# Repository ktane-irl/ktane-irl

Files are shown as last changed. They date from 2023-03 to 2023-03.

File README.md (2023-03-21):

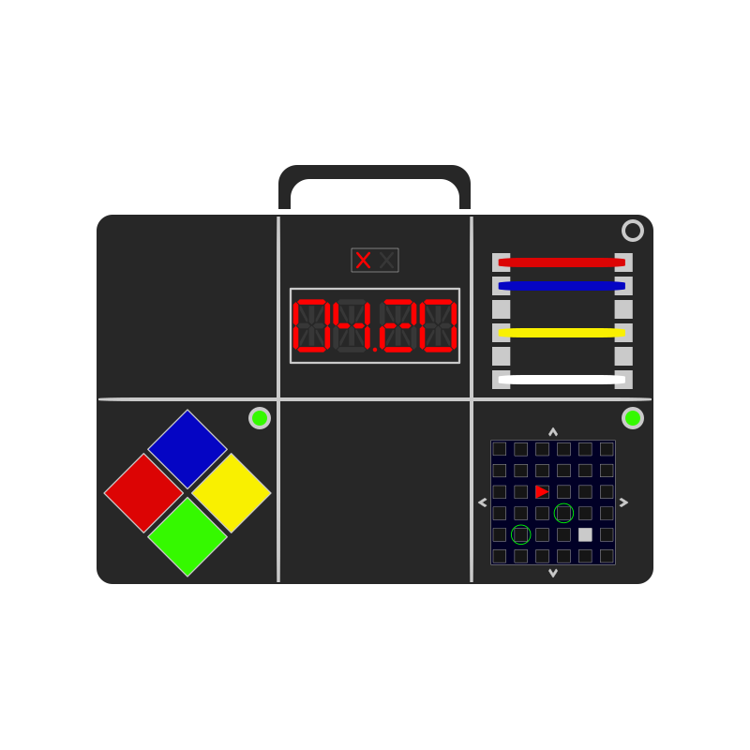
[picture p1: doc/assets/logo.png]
<h1> 

# KTANEirl

</h1>

[Keep Talking and nobody explodes](https://keeptalkinggame.com/) in real life!

<br>

KTANEirl is a modular in-hardware implementation of the famous puzzle video game KTANE.

## Modules

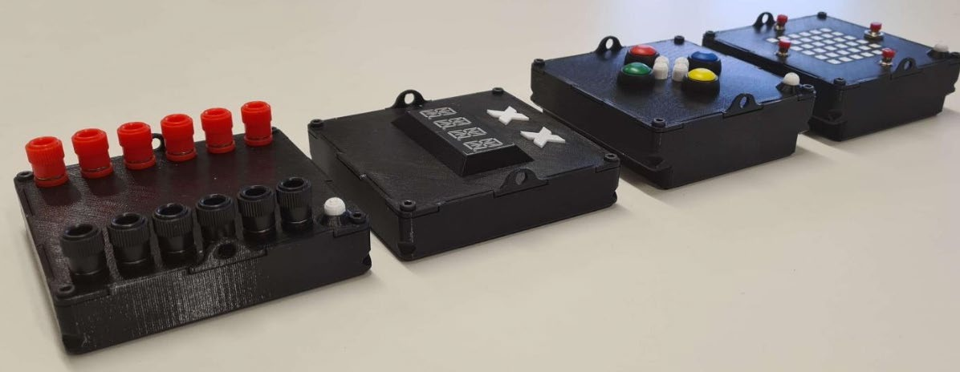
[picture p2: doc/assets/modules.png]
modules


The modules information can be found in the [modules](modules/README.md) folder.

## Master

The master information can be found in the [master](master/README.md) folder.

## Contributors

* Module implementations: [@FinnArtmann](https://github.com/FinnArtmann), [@andreasforstner](https://github.com/andreasforstner), [@RebekkaSeidenschwand](https://github.com/RebekkaSeidenschwand)
* package controller: [@ZaykorDE](https://github.com/ZaykorDE)
* module logic and game logic: [@Emergency1999](https://github.com/Emergency1999)
* API: [@thomasniefanger](https://github.com/thomasniefanger)
* frontend: [@ptrLx](https://github.com/ptrLx)
* package simulator: [@Emergency1999](https://github.com/Emergency1999)
* schematics: [@FinnArtmann](https://github.com/FinnArtmann), [@andreasforstner](https://github.com/andreasforstner), [@ZaykorDE](https://github.com/ZaykorDE)
* 3D modeling: [@Emergency1999](https://github.com/Emergency1999)

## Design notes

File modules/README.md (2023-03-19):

# KTANEirl Modules

This folder structure contains the [**firmware code**](#firmware), [**circuit schematics**](#circuit-schematics) and [**3D files**](#3d-files) of the KTANEirl modules.

## Firmware

This code is the firmware for the KTANEirl project. Each module has a specific firmware code  which runs on the module's Arduino nano.

### Requirements

#### VSCode with PlatformIO

- Install VSCode from the official [Website](https://code.visualstudio.com/)

- install the [PlatformIO IDE](https://marketplace.visualstudio.com/items?itemName=platformio.platformio-ide) extension from the marketplace via the extensions menu on the left on VSCode

#### Install dependencies

Dependencies should be installed automatically by PlatformIO.
It uses a *platform.ini* file from each specific module directory to find the required dependencies.

### Usage

Open the [firmware.code-workspace](../firmware.code-workspace)

### Build

- Select the Module to be built in the bottom bar in VSCode
- Build it using CTRL+ALT+B

### Deploy

- Connect your device to the USB port of the Arduino nano
- Upload the firmware with the keybinding CTRL+ALT+U

### Monitor

- Open the Serial Port Monitor with CTRL+ALT+S

## Circuit schematics

The circuit schematics are made with KiCad. To open the schematics, you need to install KiCad from the official [Website](https://kicad.org/).

## 3D files

The 3D files are created in Onshape and exported as STL files.

To add or change 3D files, you need to create an account on [Onshape](https://www.onshape.com/). Then you can copy [this project](https://cad.onshape.com/documents/d60e5291216102ee16b1bc50/w/64ba86776bbcf32b675bc0db/e/fd5f7a77dd2c26ad647590be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) and make your changes.

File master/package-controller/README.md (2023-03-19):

# KTANEirl Package Controller

This code is the package controller for the KTANEirl project. It is designed to run on a raspberry pi and create a connection with the backend through TCP and with the modules thorugh SPI.

## Setup
For the setup of the package controller two libarires must be installed. In order to do so the following two scripts need to be executed on the raspberry pi:
* install-bcm.sh
* install-sockpp.sh

## Usage
To start the the package controlle the file spi-package-controller needs to be executed. This can be done with the following command:
* sudo spi-package-controller

## Building the code
For building the project a Makefile has been created. After changed to the code this can be executed through the following command:
* make

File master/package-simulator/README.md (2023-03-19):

# KTANEirl Package Simulator

This code is the package simulator for the KTANEirl project. It is designed to run on a raspberry pi and send simulated SPI commands to the connected module.

## Setup

### Install dependencies

```bash
yarn install
```

## Usage

First, change the byte string, which should represent the SPI command, in [app.ts](src/app.ts).

Then, start the simulator:

```bash
yarn serve
```

The output then shows the sent and received bytes from the module.

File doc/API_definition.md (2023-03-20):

# /api

## /api/status

### /api/connected-modules

> GET

```json
{
    "slot_0": {
        "name": "Case",
        "version": 1,
        "configuration_target_reached": false,
    },
    "slot_1": {
        "name": "ClockModule",
        "version": 1,
        "configuration_target_reached": true
    },
    "slot_2": {
        "name": "TheButton",
        "version": 1,
        "configuration_target_reached": false
    },
    "slot_3": {
        "name": "Keypads",
        "version": 1,
        "configuration_target_reached": false
    },
    "slot_4": {
        "name": "Wires",
        "version": 1,
        "configuration_target_reached": false
    },
    "slot_5": {
        "name": "not_connected",
        "version": 0,
        "configuration_target_reached": true
    },
    "slot_6": {
        "name": "not_connected",
        "version": 0,
        "configuration_target_reached": true
    },
    "slot_7": {
        "name": "TheButton",
        "version": 1,
        "configuration_target_reached": false
    },
    "slot_8": {
        "name": "not_connected",
        "version": 0,
        "configuration_target_reached": true
    },
    "slot_9": {
        "name": "not_connected",
        "version": 0,
        "configuration_target_reached": true
    },
    "slot_10": {
        "name": "CapacitorDischarge",
        "version": 1,
        "configuration_target_reached": false
    },
    "slot_11": {
        "name": "not_connected",
        "version": 0,
        "configuration_target_reached": true
    },
    "slot_12": {
        "name": "not_connected",
        "version": 0,
        "configuration_target_reached": true
    }   
}
```

### /api/Case/1/[0-12]

> GET

```json
{
  "serialNumber": "AL50F2",
  "indicatorText": ["Empty","SND","CLR","CAR"],
  "indicatorLed": [false, false, false, false, false],
  "batteries": [true,false,true,false,true,false],
  "ports": {
    "DVI_D": false,
    "Parallel": true,
    "PS_2": false,
    "Serial": false,
    "Cinch": false
    }
}
```

> PUT

```json
{
   "indicatorLed": [true, false, true, true, true]
}
```

### /api/ClockModule/1/[0-12]

> GET

```json
{
    "secondsLeft": 20,
    "strikeLed": [true, false]    
}
```

> PUT

```json
{
    "secondsLeft": 20,
    "strikeLed": [true, false]  
}
```

### /api/Wires/1/[0-12]

> GET

<!-- color 0 means not connected -->
<!-- see wires type in common -->

```json
{
    "wiresColor": [0, 1, 2, 4, 5, 6],
    "statusLed": {
        "red": true,
        "green": false
    }
}

> PUT

```json
{   
    "statusLed": {
        "red": false,
        "green": false
    }
}
```

### /api/SimonSays/1/[0-12]

> GET

```json
{
    "led":{
        "red": true,
        "green": false,
        "yellow": false,
        "blue": false
    },
    "button": {
        "red": true,
        "green": false,
        "yellow": false,
        "blue": false
    },
    "statusLed": {
        "red": true,
        "green": false
    }
}
```

> PUT

```json
{
    "led": {
        "red": true,
        "green": false,
        "yellow": false,
        "blue": false
    },
    "statusLed": {
        "red": false,
        "green": false
    }
}
```

### /api/Mazes/1/[0-12]

> GET

```json
{
    "button": {
        "top": true,
        "right": false,
        "bottom": false,
        "left": false
    },
    "wallMatrix": [[true],[false]],
    "special": {
        "circle1": {"x": 1, "y": 2},
        "circle2": {"x": 3, "y": 4},
        "player": {"x": 5, "y": 6},
        "target": {"x": 7, "y": 8}
    },
    "statusLed": {
        "red": true,
        "green": false
    }
}
```

> PUT

```json
{
    "wallMatrix": [[true],[false]],
    "special": {
        "circle1": {"x": 1, "y": 2},
        "circle2": {"x": 3, "y": 4},
        "player": {"x": 5, "y": 6},
        "target": {"x": 7, "y": 8}
    },
    "statusLed": {
        "red": true,
        "green": false
    }
    
}
```

<!-- ### /api/Button/1/[0-12]

not implemented.

### /api/Keypad/1/[0-12]

not implemented.

### /api/WhosOnFirst/1/[0-12]

not implemented.

### /api/Memory/1/[0-12]

not implemented.

### /api/MorseCode/1/[0-12]

not implemented.

### /api/ComplicatedWires/1/[0-12]

not implemented.

### /api/WireSequences/1/[0-12]

not implemented.

### /api/Passwords/1/[0-12]

not implemented.

### /api/VentingGas/1/[0-12]

not implemented.

### /api/Knobs/1/[0-12]

not implemented.

### /api/CapacitorDischarge/1/[0-12]

not implemented. -->

## /api/play

### /api/play/config

> PUT

```json
{
    "available_modules": [
        {"name": "Wires", "count": 0},
        {"name": "TheButton", "count": 0},
        {"name": "Keypads", "count": 0},
        {"name": "SimonSays", "count": 1},
        {"name": "WhosOnFirst", "count": 0},
        {"name": "Memory", "count": 1},
        {"name": "MorseCode", "count": 2},
        {"name": "ComplicatedWires", "count": 1},
        {"name": "WireSequences", "count": 2},
        {"name": "Mazes", "count": 0},
        {"name": "Passwords", "count": 2},
        {"name": "VentingGas", "count": 0},
        {"name": "CapacitorDischarge", "count": 0},
        {"name": "Knobs", "count": 0}
    ],
    "count_of_wished_modules": 5,
    "seconds_to_play": 0,
    "severity_level": 1
}
```

(Response of generated configuration)

> GET

```json
["Wires", "SimonSays", "Wires", "TheButton"]
```

### /api/play/config/Case/1/[0-12]

> GET

```json
{
    "caseTarget":{
        "serialNumber": "AL5OF2",
        "indicatorText": ["SND", "CLR", "CAR", "NSA", "SIG"],
        "indicatorLed":[true,false,true,false,false],
        "batteries": [true, false, false, false, false, false],
        "ports": {
            "DVI-D" : false,
            "Parallel": true,
            "PS/2": false,
            "RJ-45" : false,
            "Serial": false,
            "Cinch": false
        }
    },
    "caseState":{
        "serialNumber": "JG0IZ1",
        "indicatorText": ["IND", "MSA", "FRk", "NSA", "SIG"],
        "indicatorLed":[false,false,true,false,false],
        "batteries": [true, true, true, false, false, false],
        "ports": {
            "DVI-D" : true,
            "Parallel": false,
            "PS/2": false,
            "RJ-45" : false,
            "Serial": false,
            "Cinch": false
        }
    }
}
```

### /api/play/config/Wires/1/[0-12]

> GET

```json
// "black" / "blue" / "" / "red" / "white" / "yellow"
{
    "wiresTarget":{

        "statusLed":{
            "red": false,
            "green": false
        },
        "wiresColor":[4,4,1,5,1,3]
    },
    "wiresState":{

        "statusLed":{
            "red": false,
            "green": true
        },
        "wiresColor":[2,3,1,4,5,3]
    }
}
```

<!-- ### /api/play/config/TheButton/1/[0-12]

not implemented.

### /api/play/config/Keypads/1/[0-12]

not implemented.

### /api/play/config/WhosOnFirst/1/[0-12]

not implemented.

### /api/play/config/Memory/1/[0-12]

not implemented.

### /api/play/config/MorseCode/1/[0-12]

not implemented.

### /api/play/config/ComplicatedWires/1/[0-12]

not implemented.

### /api/play/config/WireSequences/1/[0-12]

not implemented.

### /api/play/config/Mazes/1/[0-12]

not implemented.

### /api/play/config/Passwords/1/[0-12]

not implemented.

### /api/play/config/VentingGas/1/[0-12]

not implemented.

### /api/play/config/CapacitorDischarge/1/[0-12]

not implemented.

### /api/play/config/Knobs/1/[0-12]

not implemented. -->

### /api/play/SetGameState

**gamemodes**:

* test_idle
* setup
* playing

> PUT

```json
{
    "gamemode": "playing"
}
```

> GET

```json
{
    "gamemode": "playing"
}
```

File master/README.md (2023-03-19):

# KTANEirl Master

master components

This folder contains all software running on the raspberry pi. This includes the [frontend](frontend/README.md), the [backend](backend/README.md) and the [package-controller](package-controller/README.md).

To setup the pi, run the [setup script](setup-pi.sh) on it.

To test basic firmware functionality, use the [package-simulator](package-simulator/README.md).

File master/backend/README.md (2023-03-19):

# KTANEirl Backend

This code is the backend for the KTANEirl project. It is designed to run on a raspberry pi and communicate with the frontend via the API.

## Requirements

### **Node.js >= 18.12.0**

Download from [nodejs.org](https://nodejs.org/en/download/) or use

```bash
curl -fsSL https://deb.nodesource.com/setup_18.x | sudo -E bash -
sudo apt-get install -y nodejs
```

on Linux Ubuntu or use the [setup script](../setup-pi.sh) on the pi.

### **yarn >= 1.22.19**

use this to install yarn:

```bash
npm install -g yarn
```

## Setup

### Install dependencies

```bash
yarn install
```

## Usage

### Start in normal mode

This command builds and the starts the backend.

```bash
yarn serve
```

### Start in simulator mode

**Start with API dummy-mode:**  
Use this if the Backend does not yet have the needed Module.

```bash
yarn serve-api
```

**Start with simulated SPI:**  
If the Backend class is fully implemented, use this to simulate the SPI communication.
The simulated commands can be changed in [app.sim.ts](src/app.sim.ts)

```bash
yarn serve-sim
```

### Other commands

| Command | Description |
| --- | --- |
| `yarn build` | Build the project |
| `yarn tsc` | Automatically build the project on changes |
| `yarn lint` | Lint the project |
| `yarn auto` | Run in normal mode and restart on changes |
| `yarn auto-api` | Run in dummy-mode and restart on changes |
| `yarn auto-sim` | Run in simulated SPI mode and restart on changes |
| `yarn clean` | Delete all build files |
| `yarn test` | Run all tests |
| `yarn autotest` | Automatically run all tests on changes |

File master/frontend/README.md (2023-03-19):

# KTANEirl Frontend

This code is the frontend for the KTANEirl project. It is designed to run on a raspberry pi and communicate with the backend via the API.

## get started

* setup and start dev container (See <https://code.visualstudio.com/docs/devcontainers/create-dev-container>)
* `cd master/frontend`
* `yarn`
* `yarn serve`

<!-- ## create a vue app (don't do this, it's already created)
* `cd master`
* `vue create ktaneirl`  
  * Manually select features
  * Select Babel, TypeScript, Progressive Web App (PWA) Support, Router, Linter / Formatter, Unit Testing
  * 2.x (as vuetify does not support vue3 currently)
  * Confirm everything
* `cd ktaneirl`
* `vue add -D vuetify`
* `yarn add express typescript ts-node nodemon @types/node express @types/express`
* `yarn serve` -->

## add a module / version

1. `components/testmode`: Copy VersionComponentDummy and align to other module code
2. `views/TestmodeView.vue`: Import component; add to components const; add case in show_component_dialog

## initial setup for production

to setup backend and frontend on the pi, run the [setup script](../setup-pi.sh) on it.

## deployment

to deploy the frontend, run the [deploy script](../deploy-frontend.sh) on your local machine.

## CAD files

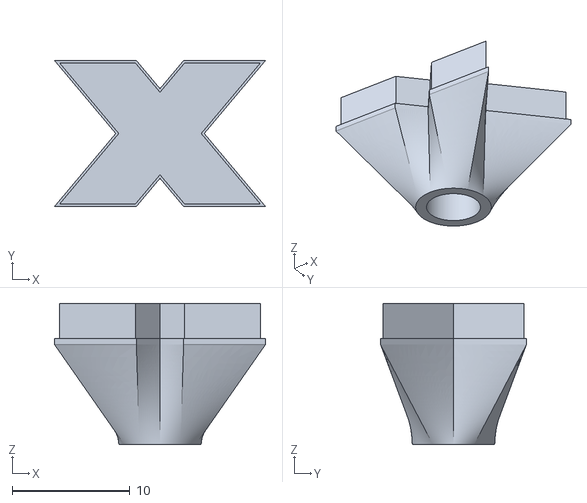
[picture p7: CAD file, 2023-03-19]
modules/01-clockModule/CM01-3d-design/CM01-Xled.stl
17.9 x 12.4 x 12.0

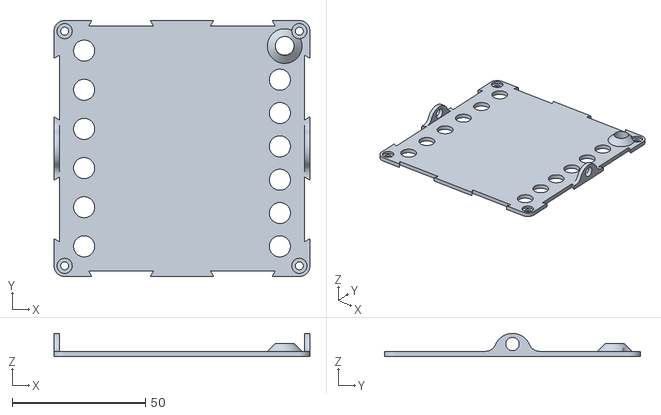
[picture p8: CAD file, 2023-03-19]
modules/02-wires/WI01-3d-design/WI01-ModuleTop.stl
96.0 x 96.0 x 8.70

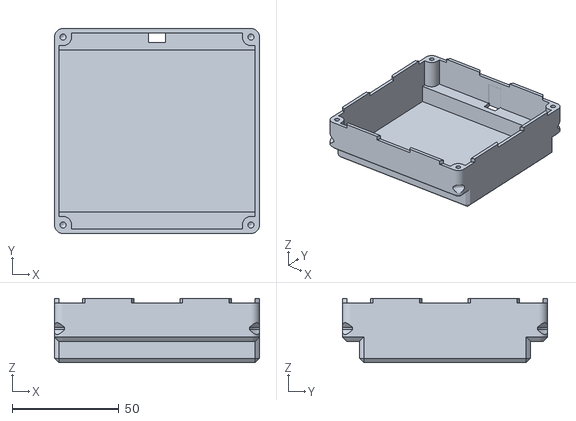
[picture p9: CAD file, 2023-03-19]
modules/05-simonSays/SS01-3d-design/SS01-ModuleBottom.stl
96.0 x 96.0 x 30.2

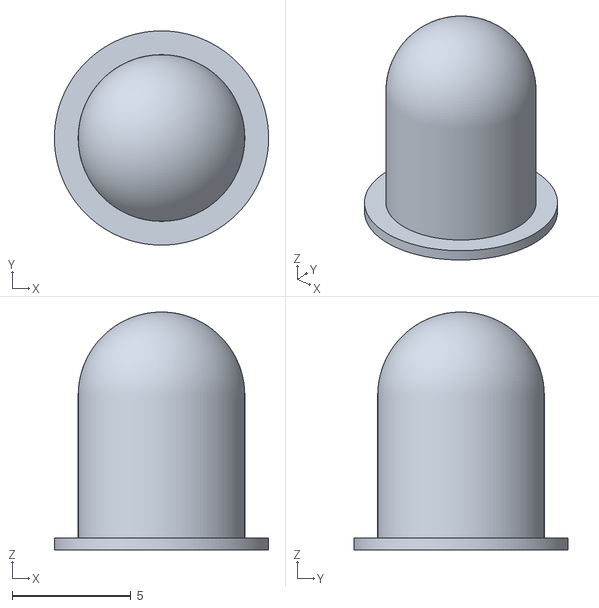
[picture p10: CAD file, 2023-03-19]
modules/02-wires/WI01-3d-design/WI01-LED.stl
9.00 x 9.00 x 10.0

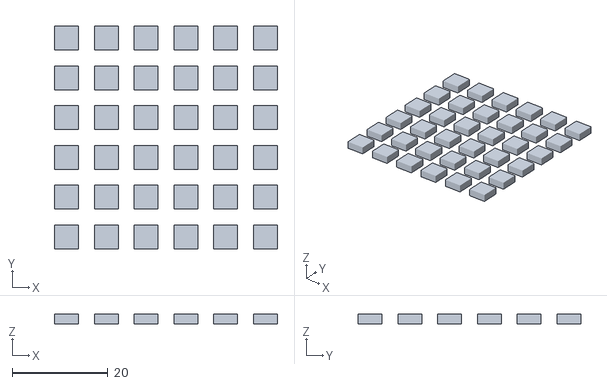
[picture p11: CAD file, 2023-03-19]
modules/11-mazes/MA01-3d-design/MA01-ModuleTop-White.stl
46.5 x 46.5 x 2.00

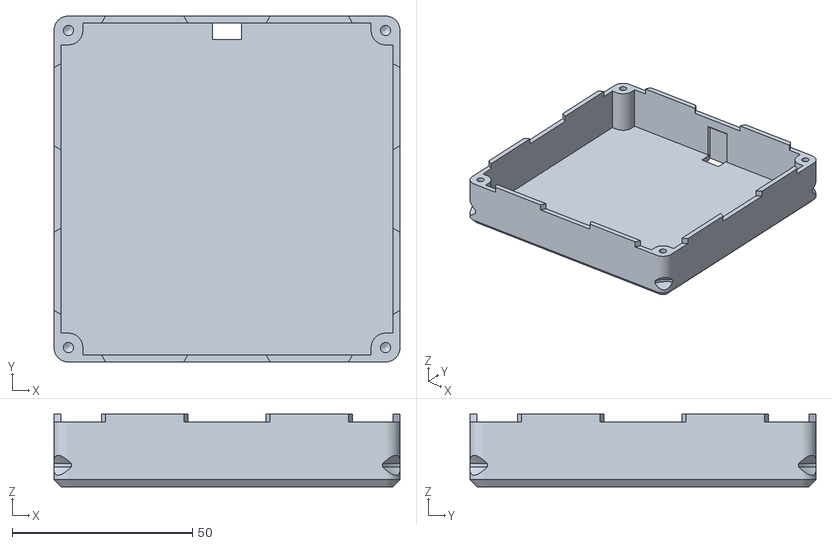
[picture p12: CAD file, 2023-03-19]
modules/01-clockModule/CM01-3d-design/CM01-ModuleBottom.stl
96.0 x 96.0 x 20.2

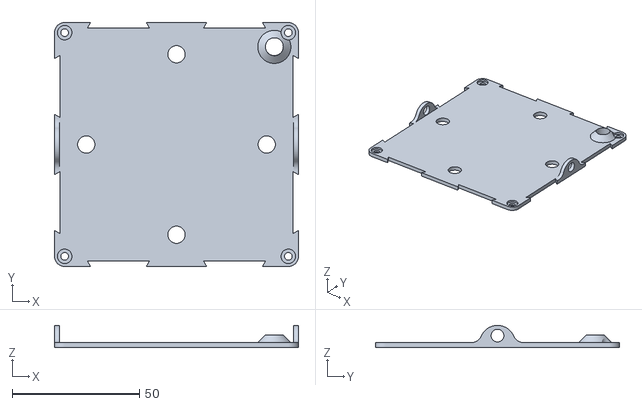
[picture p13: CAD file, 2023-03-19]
modules/11-mazes/MA01-3d-design/MA01-ModuleTop.stl
96.0 x 96.0 x 8.70

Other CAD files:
modules/11-mazes/MA01-3d-design/MA01-ModuleTop-Black.stl
modules/01-clockModule/CM01-3d-design/CM01-ModuleTop.stl
modules/05-simonSays/SS01-3d-design/SS01-ModuleTop.stl

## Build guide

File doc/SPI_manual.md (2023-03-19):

# SPI manual

all messages consist of 4 parts:

* 1     byte  CMD:  the command describing the action to be taken (0x01 - 0xFE)
* 1     byte  LEN:  the length of the DATA bytes
* 0-255 bytes DATA: the data to be sent or received
* 1     byte  CRC:  the CRC of the message, suing the Arduino internal CRC8 function

All Commands sent from client to the master need to be acknowledged by the master. The master will send a message with the same CMD as the original message, LEN = 1 and DATA with the event counter from the client message.

There is one exception for the SPI test:  
When CMD=0xEA, LEN=0xA5  
The SPI tests consists of 255 data bytes, using this algorithm:  
`data_0 = 0x01, data_i = (data_(i-1) * 5 + 1) % 256`  
As soon as the SPI test is done, the master and the client create error count messages (see [global](#global)).  
The client sends this as usual over SPI, the master injects the package as if it were received per SPI.

## IDs

### Module IDs

| ID dec | SHORT | NAME |
| -----: | ----: | --- |
| 0 | CA | Case |
| 1 | CM | Clock Module |
| 2 | WI | Wires |
| 3 | TB | The Button |
| 4 | KP | Keypads |
| 5 | SS | Simon Says |
| 6 | WF | Who’s on First |
| 7 | ME | Memory |
| 8 | MC | Morse Code |
| 9 | CW | Complicated Wires |
| 10 | WS | Wire Sequences |
| 11 | MA | Mazes |
| 12 | PW | Passwords |
| 16 | VG | Venting Gas |
| 17 | CD | Capacitor Discharge |
| 18 | KN | Knobs |

### Color IDs (3 bit)

| ID | COLOR |
| ----- | --- |
| 0b000 | not connected / off |
| 0b001 | black |
| 0b010 | blue |
| 0b011 | green |
| 0b100 | red |
| 0b101 | yellow |
| 0b110 | white |

### Error codes (8 bit)

| ID  | ERROR CODE |
| --- | --- |
| 0 | NoError |
| 1 | CRCError |
| 2 | InvalidCommand |
| 3 | InvalidDataLength |
| 4 | AcknowledgeError |
| 5 | BufferOverflow |
| | |
| 10  | DisplayConnectionError |

## GLOBAL

MASTER->SLAVE
| CMD  | NAME |  LEN | DATA DESCRIPTION |
| ---- | --- | ---: | --- |
| 0x00 | reserved for NO_CMD | | |
| 0xFF | reserved for NOT_CONNECTED | | |
| 0xEA | reserved for SPI test | | |
| | | | |
| 0xFE | ACK Error code | 1 | error counter |
| 0xFD | ACK module initialization  | 1 | ID |
| 0xFC | request module reset | 0 | |

SLAVE->MASTER
| CMD  | NAME | SENT CONDITION |  LEN | DATA DESCRIPTION |
| ---- | --- | --- | ---: | --- |
| 0x00 | reserved for NO_CMD | | | |
| 0xFF | reserved for NOT_CONNECTED | | | |
| 0xEA | reserved for SPI test | | | |
| 0xEB | Error count on MOSI (sent by slave) | on SPI test done | 1 | number of byte errors |
| 0xEC | Error count on MISO (injected by master) | on SPI test done | 1 | number of byte errors |
| | | | | |
| 0xFE | Error code | on error | 2 | error counter, error code |
| 0xFD | module ID+version | when not initialized | 2 | ID, version |

## 00 Case

### CA-01

MASTER->SLAVE
| CMD  | NAME |  LEN | DATA DESCRIPTION |
| ---- | --- | ---: | --- |
| 0x01 | set 5 indicator lights | 1 | 0b___43210: |
| | | | 0-4: indicator (1 = ON, 0 = OFF) |
| 0x02 | ACK 6 battery slot states | 1 | counter |

SLAVE->MASTER
| CMD  | NAME | SENT CONDITION |  LEN | DATA DESCRIPTION |
| ---- | --- | --- | ---: | --- |
| 0x02 | 6 battery slot states | when initialized or changed | 2 | counter, 0b__543210: |
| | | | | 0-5: battery slots (1 = FILLED, 0 = EMPTY) |

## 01 Clock Module

### CM-01

MASTER->SLAVE
| CMD  | NAME |  LEN | DATA DESCRIPTION |
| ---- | --- | ---: | --- |
| 0x01 | game time left and errors | 2 | 0bLR__TTTT 0bTTTTTTTT: |
| | | | L = left "X" LED (1 = ON, 0 = OFF) |
| | | | R = right "X" LED (1 = ON, 0 = OFF) |
| | | | T = time left in seconds (12 bit, MSB left to LSB right) |

## 02 Wires

### WI-01

MASTER->SLAVE
| CMD  | NAME |  LEN | DATA DESCRIPTION |
| ---- | --- | ---: | --- |
| 0x01 | RG LED | 1 | 0b______RG: |
| | | | R = Red LED (1 = ON, 0 = OFF) |
| | | | G = Green LED (1 = ON, 0 = OFF) |
| 0x02 | ACK wire states | 1 | counter |

SLAVE->MASTER
| CMD  | NAME | SENT CONDITION |  LEN | DATA DESCRIPTION |
| ---- | --- | --- | ---: | --- |
| 0x02 | wire states | when initialized or changed | 4 | counter, 0b__555444 0b__333222 0b__111000: |
| | | | | 0=top to 5=bottom: [color IDs](#color-ids-3-bit) |

## 03 The Button

## 04 Keypads

## 05 Simon Says

### SS-01

MASTER->SLAVE
| CMD  | NAME |  LEN | DATA DESCRIPTION |
| ---- | --- | ---: | --- |
| 0x01 | RG LED | 1 | 0b______RG: |
| | | | R = Red LED (1 = ON, 0 = OFF) |
| | | | G = Green LED (1 = ON, 0 = OFF)  |
| 0x02 | LED states | 1 | 0b____BYGR |
| | | | B = blue LED (1 = ON, 0 = OFF) |
| | | | Y = yellow LED (1 = ON, 0 = OFF) |
| | | | G = green LED  (1 = ON, 0 = OFF) |
| | | | R = red LED (1 = ON, 0 = OFF) |
| 0x03 | ACK button states | 1 | counter |

SLAVE->MASTER
| CMD  | NAME | SENT CONDITION |  LEN | DATA DESCRIPTION |
| ---- | --- | --- | ---: | --- |
| 0x03 | button states | when initialized or changed | 2 | counter, 0b____BYGR |
| | | | | B = blue button state (1 = PRESSED, 0 = RELEASED) |
| | | | | Y = yellow button state (1 = PRESSED, 0 = RELEASED) |
| | | | | G = green button state  (1 = PRESSED, 0 = RELEASED) |
| | | | | R = red button state (1 = PRESSED, 0 = RELEASED) |

## 06 Who’s on First

## 07 Memory

## 08 Morse Code

### MC-01

Morse Code Frequencies:
| Code | Frequency |
| ---- | --- |
| 0x0  | 3.505 MHz |
| 0x1  | 3.515 MHz |
| 0x2  | 3.522 MHz |
| 0x3  | 3.532 MHz |
| 0x4  | 3.535 MHz |
| 0x5  | 3.542 MHz |
| 0x6  | 3.545 MHz |
| 0x7  | 3.552 MHz |
| 0x8  | 3.555 MHz |
| 0x9  | 3.565 MHz |
| 0xA  | 3.572 MHz |
| 0xB  | 3.575 MHz |
| 0xC  | 3.582 MHz |
| 0xD  | 3.592 MHz |
| 0xE  | 3.595 MHz |
| 0xF  | 3.600 MHz |

MASTER->SLAVE
| CMD  | NAME |  LEN | DATA DESCRIPTION |
| ---- | --- | ---: | --- |
| 0x01 | RG LED | 1 | 0b______RG: |
| | | | R = Red LED (1 = ON, 0 = OFF) |
| | | | G = Green LED (1 = ON, 0 = OFF) |
| 0x02 | ACK button and frequency | 1 | counter |
| 0x03 | morse led | 1 | 0b_______L: |
| | | | L = LED (1 = ON, 0 = OFF) |

SLAVE->MASTER
| CMD  | NAME | SENT CONDITION |  LEN | DATA DESCRIPTION |
| ---- | --- | --- | ---: | --- |
| 0x02 | button and frequency | when button or freq changed | 2 | counter, 0b000BFFFF |
| | | | | B = button state |
| | | | | F = frequency code  |

## 09 Complicated Wires

## 10 Wire Sequences

## 11 Mazes

### MA-01

Maze positioning:
| ROW\COL | 0 | 1 | 2 | 3 | 4 | 5 |
| --- | --- | --- | --- | --- | --- | --- |
| 0 | 0 | 1 | 2 | 3 | 4 | 5 |
| 1 | 6 | 7 | 8 | 9 | 10  | 11  |
| 2 | 12  | 13  | 14  | 15  | 16  | 17  |
| 3 | 18  | 19  | 20  | 21  | 22  | 23  |
| 4 | 24  | 25  | 26  | 27  | 28  | 29  |
| 5 | 30  | 31  | 32  | 33  | 34  | 35  |

Special type codes:
| ID  | color | DESCRIPTION |
| --- | --- | --- |
| 0 | green | Circle 1 to identify labyrinth |
| 1 | green | Circle 2 to identify labyrinth |
| 2 | white | position of player |
| 3 | red pulsing | red turning triangle position of target |

MASTER->SLAVE
| CMD  | NAME |  LEN | DATA DESCRIPTION |
| ---- | --- | ---: | --- |
| 0x01 | RG LED | 1 | 0b______RG: |
| | | | R = Red LED (1 = ON, 0 = OFF) |
| | | | G = Green LED (1 = ON, 0 = OFF) |
| 0x02 | ACK button states  | 1 | counter |
| 0x03 | Red wall positions | 5 | 0b01234567 0b89..... |
| | | | sets red positions in matrix above |
| 0x04 | Special positions  |  1-4 | 0bCCPPPPPP: |
| | | | C = Special Type code |
| | | | P = Position in maze (>35 means OFF) |

SLAVE->MASTER
| CMD  | NAME | SENT CONDITION |  LEN | DATA DESCRIPTION |
| ---- | --- | --- | ---: | --- |
| 0x02 | button states | when initialized or changed | 2 | counter, 0b____TRBL |
| | | | | T = top button state (1 = PRESSED, 0 = RELEASED) |
| | | | | R = right button state  (1 = PRESSED, 0 = RELEASED) |
| | | | | B = bottom button state (1 = PRESSED, 0 = RELEASED) |
| | | | | L = left button state (1 = PRESSED, 0 = RELEASED) |

## 12 Passwords

## 13 Venting Gas

## 14 Capacitor Discharge

## 15 Knobs

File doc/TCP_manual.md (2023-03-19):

# TCP manual

all messages consist of 4 parts:

* 1     byte  POS:  the position of the module (0-12, 0xFF=controller)
* 1     byte  CMD:  the command describing the action to be taken (0x01 - 0xFE)
* 1     byte  LEN:  the length of the DATA bytes
* 0-255 bytes DATA: the data to be sent or received

All messages from the module are acknowledged by the controller and relayed to the backend. Backend messages are directly relayed to the module. When POS is 0xFF, the message is from or to the controller.

## IDs

see in [SPI manual](SPI_manual.md#error-codes-8-bit)

## Error codes (8 bit)

| ID  | ERROR CODE |
| --- | --- |
| 0 | NoError |
| 1 | CRCErrorFromModule |
| 2 | ZeroLengthFromModule |
| 10  | IncorrectPosition |

## CONTROLLER MESSAGES

BACKEND->CONTROLLER
| CMD  | NAME |  LEN | DATA DESCRIPTION |
| ---- | --- | ---: | --- |
| 0x00 | reserved for NO_CMD | | |
| 0xFF | reserved for NOT_CONNECTED | | |
| 0xEA | reserved for SPI test | | |
| | | | |

CONTROLLER->BACKEND
| CMD  | NAME | SENT CONDITION |  LEN | DATA DESCRIPTION |
| ---- | --- | --- | ---: | --- |
| 0x00 | reserved for NO_CMD | | | |
| 0xFF | reserved for NOT_CONNECTED | | | |
| 0xEA | reserved for SPI test | | | |
| | | | | |
| 0x01 | Modules detected | looped through all clients | 2 | 0b___CCCCC 0bCCCCCCCC: |
| | | | | C = module connected on pos (1 = CONNECTED, 0 = NOT CONNECTED) |
| 0xFE | Error | | 2 | position (0xFF=controller), [ErrorCode](#error-codes-8-bit) |

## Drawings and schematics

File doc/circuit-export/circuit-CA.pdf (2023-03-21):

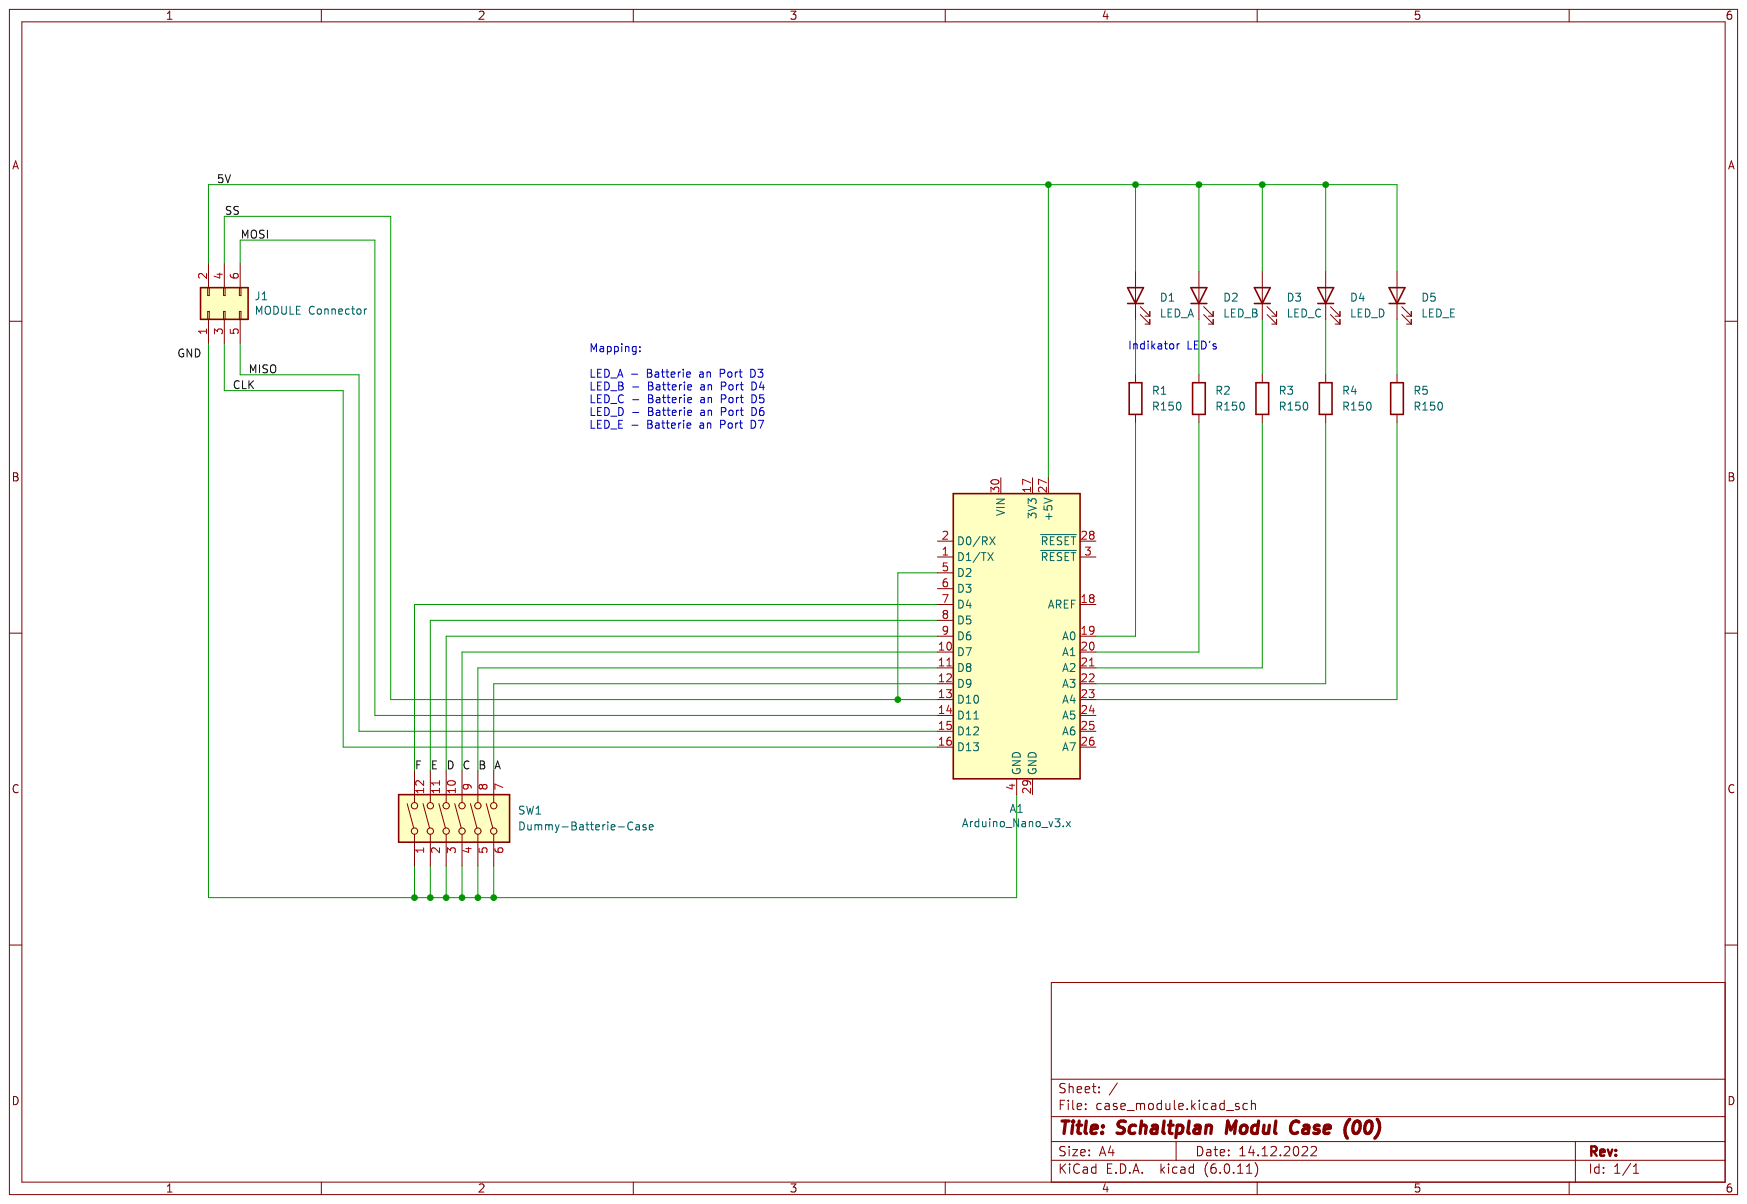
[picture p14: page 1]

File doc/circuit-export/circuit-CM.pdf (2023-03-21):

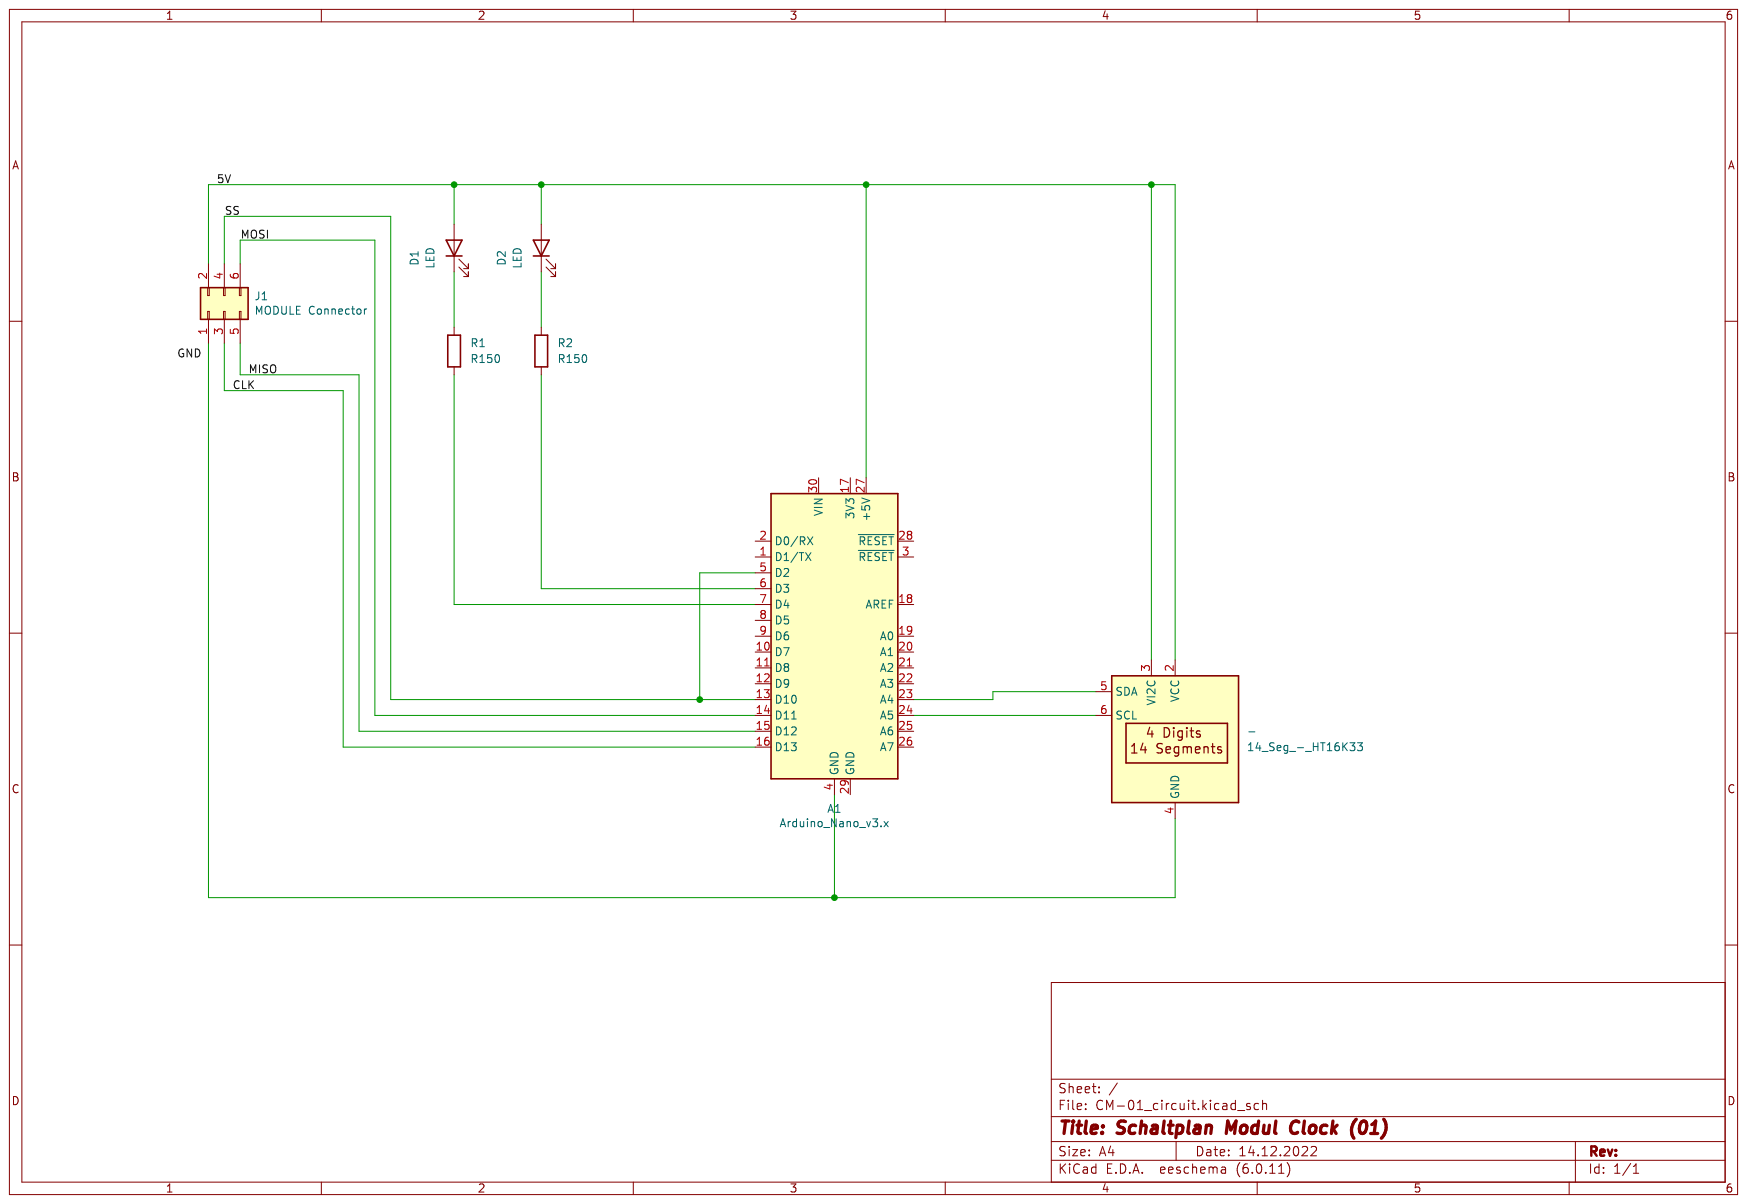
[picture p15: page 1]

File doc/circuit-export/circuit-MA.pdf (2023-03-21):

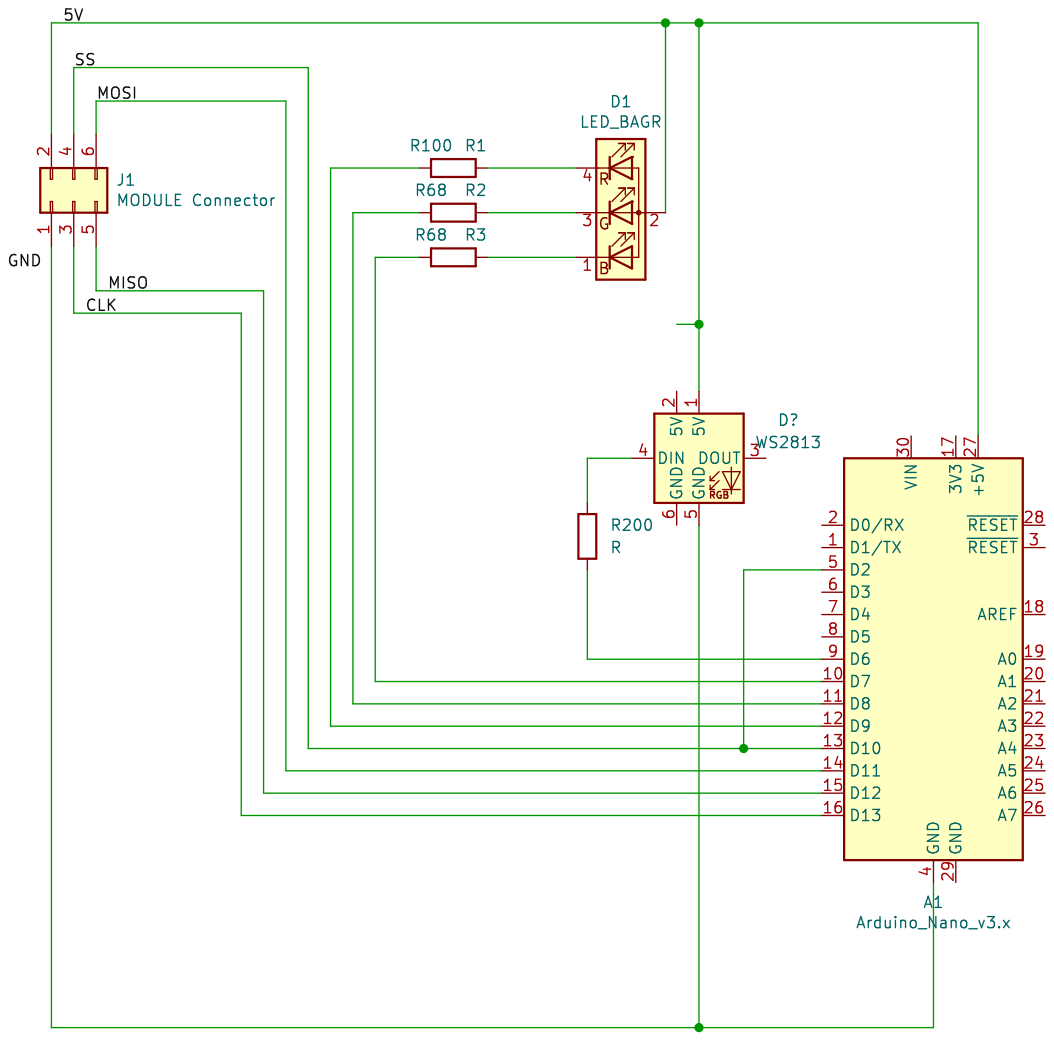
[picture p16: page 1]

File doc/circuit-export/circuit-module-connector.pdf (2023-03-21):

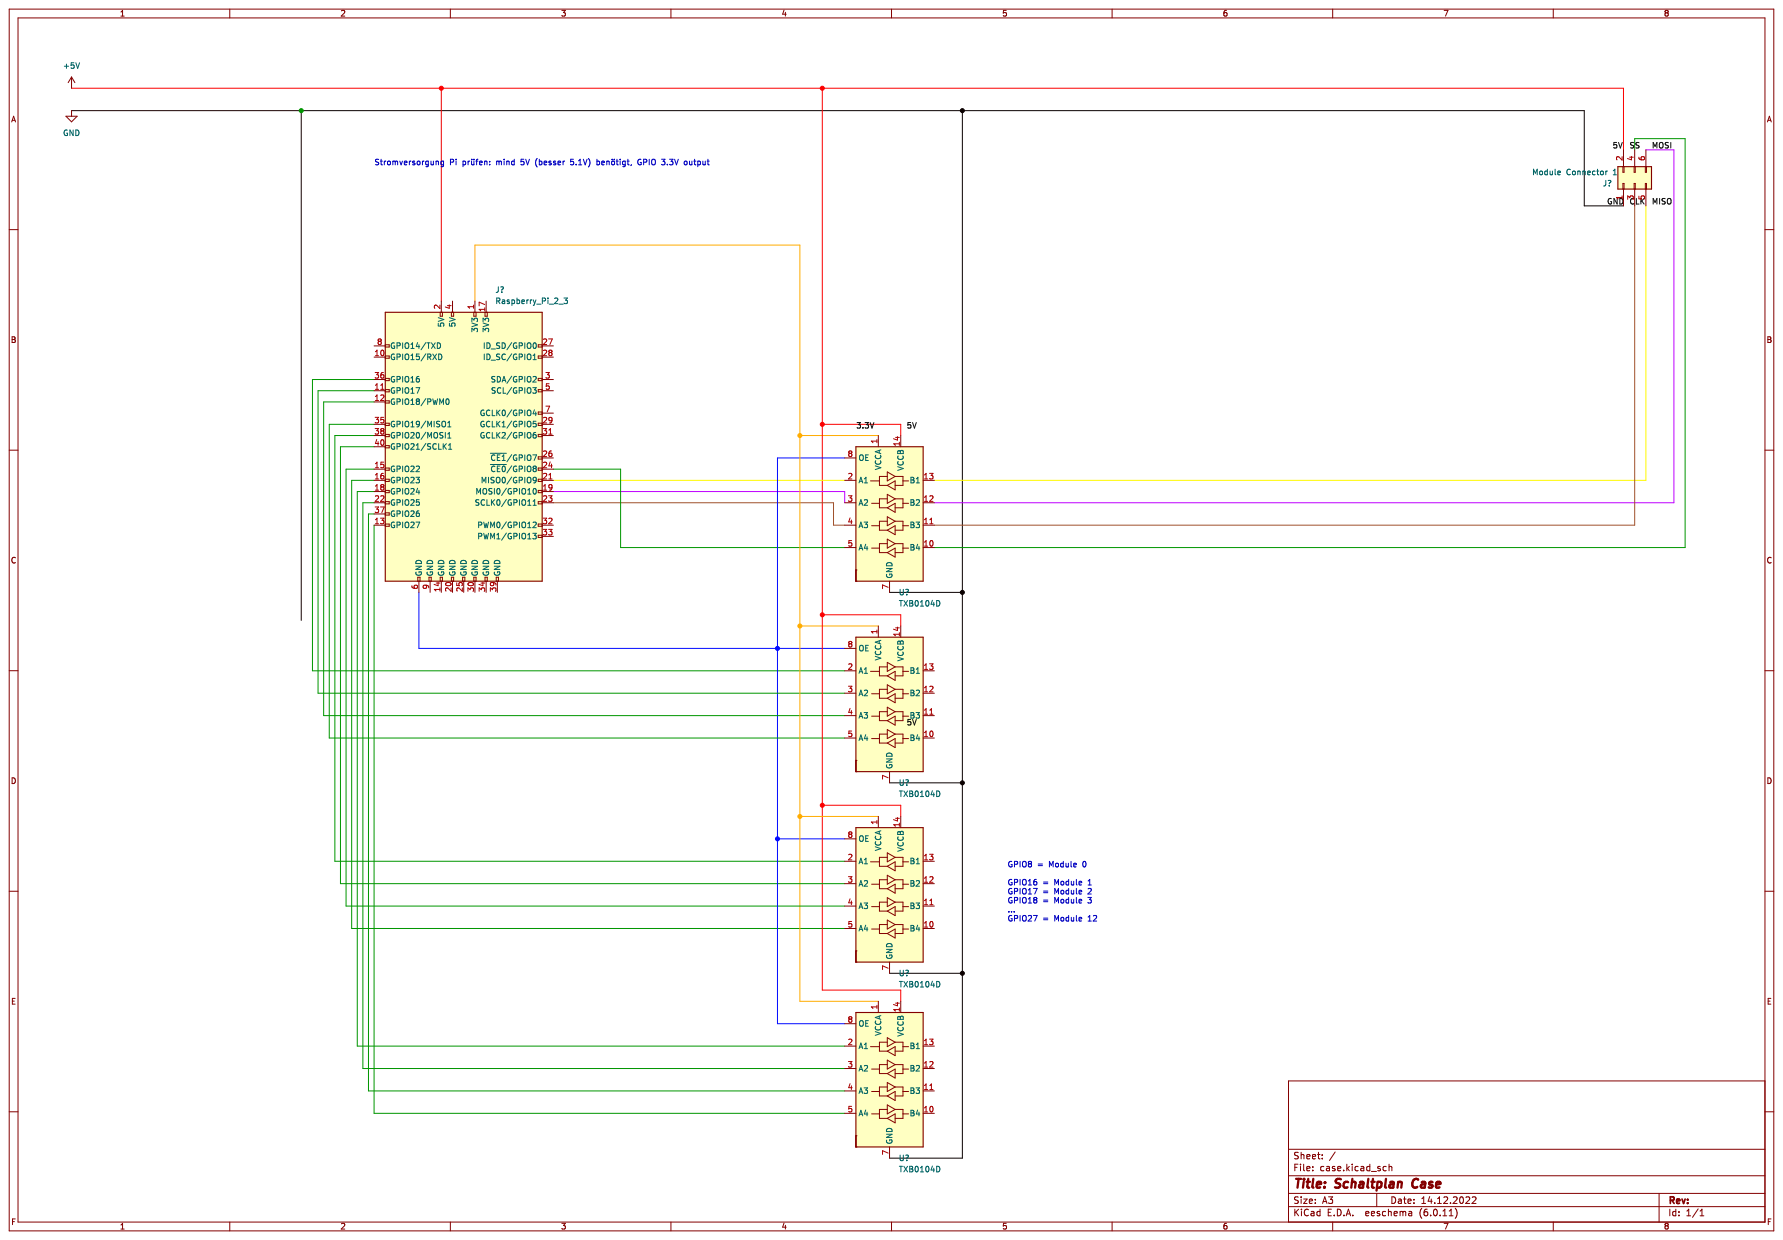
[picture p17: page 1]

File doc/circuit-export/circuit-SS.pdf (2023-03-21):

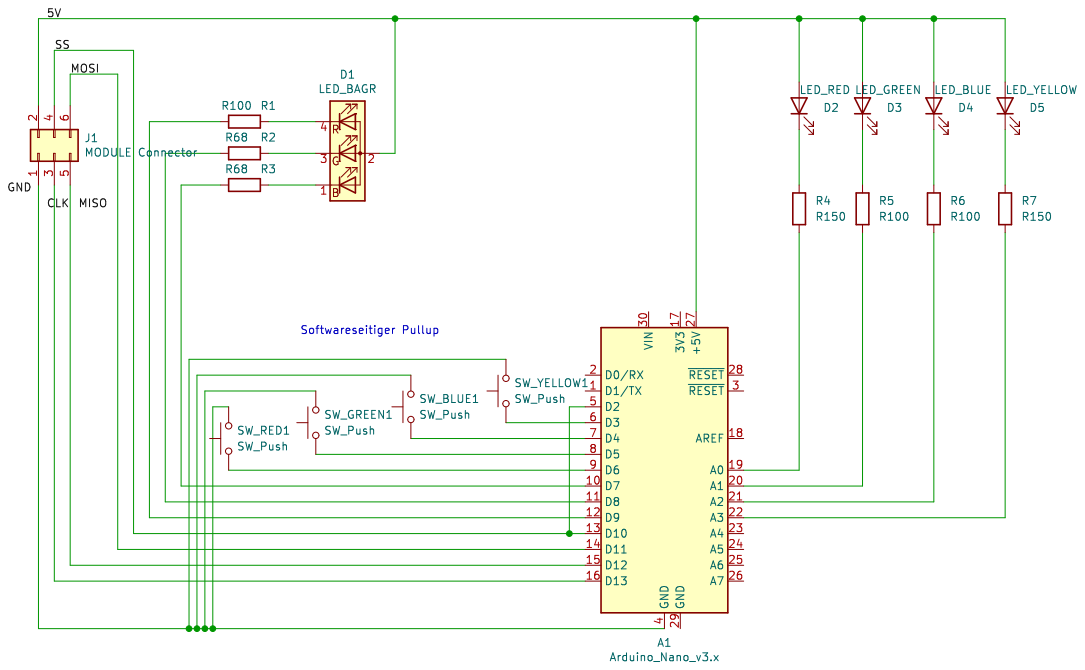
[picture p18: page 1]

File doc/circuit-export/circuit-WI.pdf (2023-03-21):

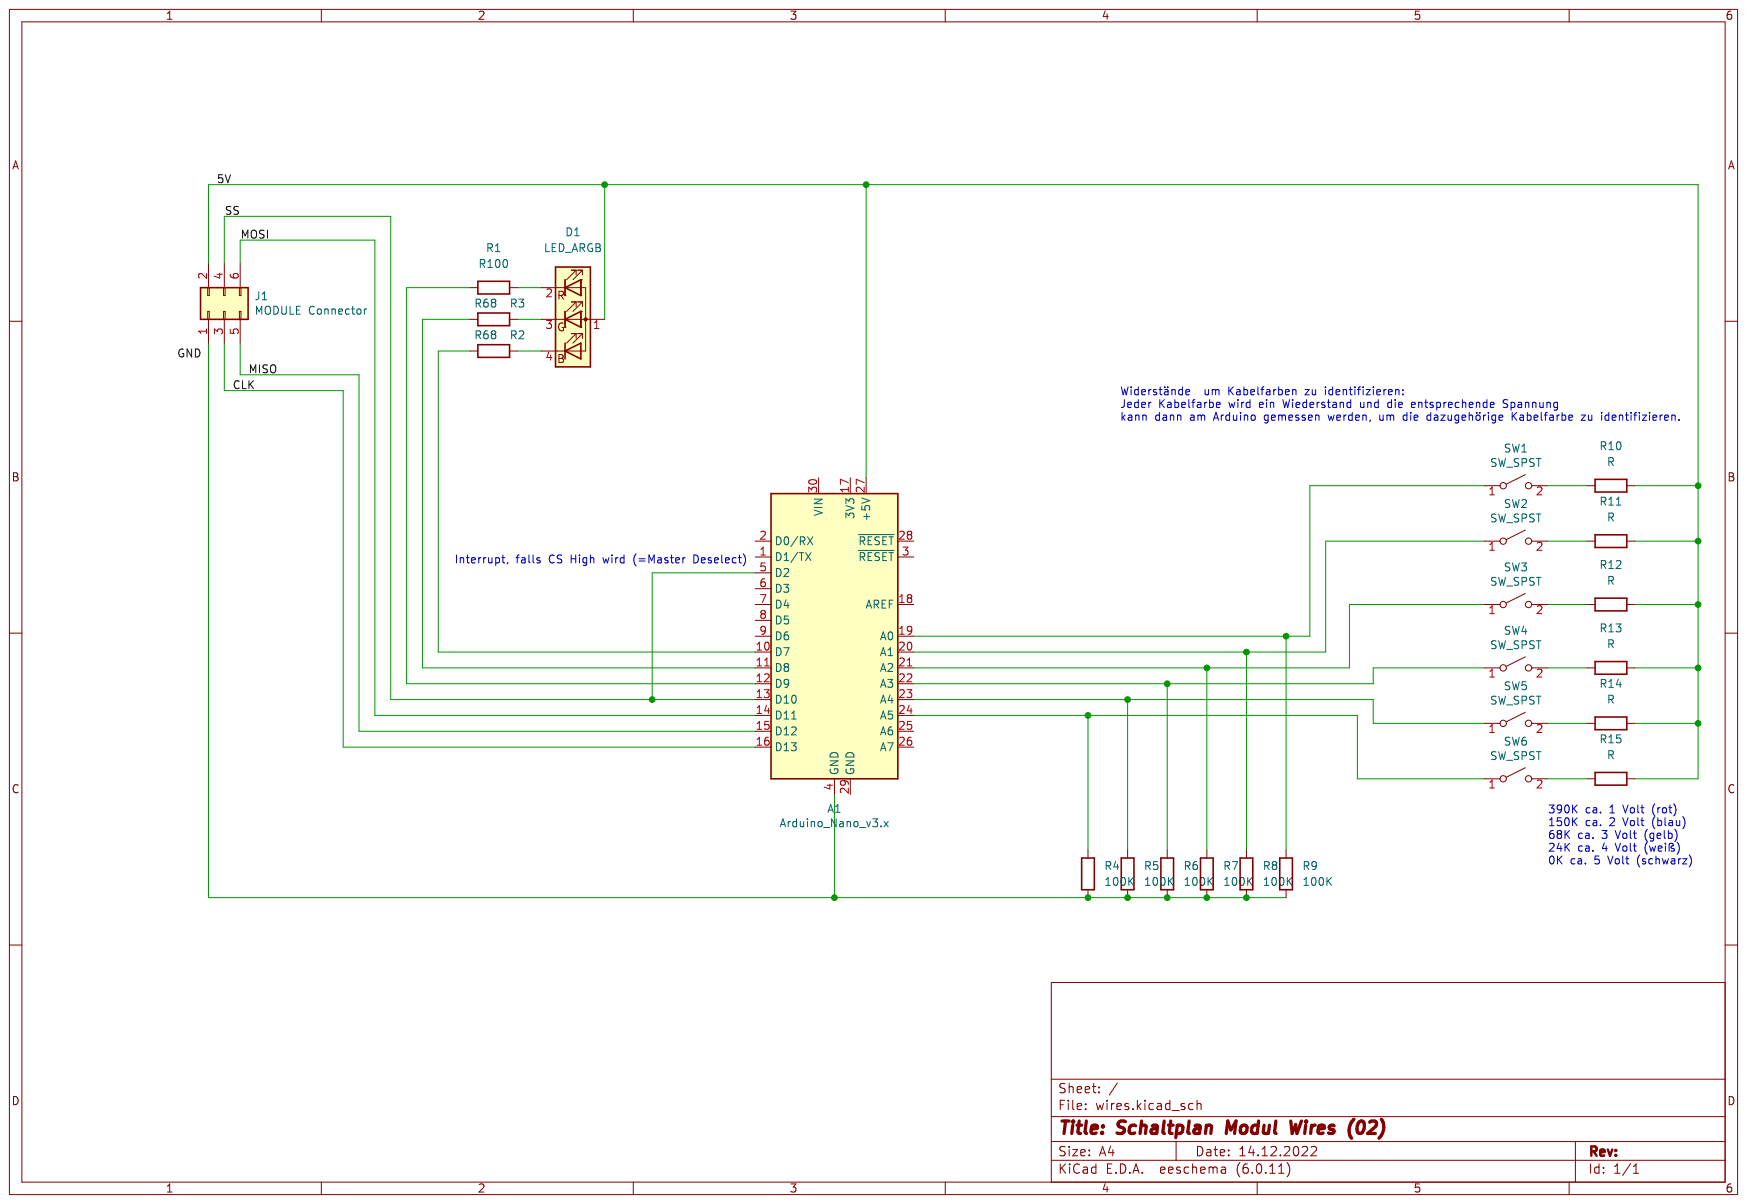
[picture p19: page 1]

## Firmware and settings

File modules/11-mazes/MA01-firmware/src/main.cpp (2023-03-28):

#include <Adafruit_NeoPixel.h>
#include <Arduino.h>
#include <SPI.h>
#include <Wire.h>
#define CIRCULAR_BUFFER_INT_SAFE  // Enable interrupt safety for CircularBuffer lib
#include <CRC8.h>                 // Link Lib: https://registry.platformio.org/libraries/robtillaart/CRC
#include <CircularBuffer.h>       // Link Lib: https://registry.platformio.org/libraries/rlogiacco/CircularBuffer
#include <Timer.h>

#include "global_module.hpp"
#include "module_events.tpp"

// --- MODULE SPECIFIC CONFIGURATION ---

// If enabled, rotate the 6x6 matrix by 90, 180 or 270 degrees counter-clockwise
// #define ROTATE_90
// #define ROTATE_180
// #define ROTATE_270

// Module ID and Module Version
#define MODULE_ID 11
#define MODULE_VERSION 1

// --- MODULE SPECIFIC COMMANDS ---

// Master to Slave
#define CMDMM_RG_LED 0x01
#define CMDMM_ACK_BUTTON_STATES 0x02
#define CMDMM_RED_WALL_POSITIONS 0x03
#define CMDMM_SPECIAL_POSITIONS 0x04

// Slave to Master
#define CMDMS_BUTTON_STATES 0x02

// --- PIN CONFIGURATION ---
#define MATRIX_DATA_IN 6
// #define MATRIX_DATA_OUT

// See status_led.hpp for status led configurations

// TRBL
#define BUTTON_TOP 5     // 7 //TODO was is wrong in Code or Circuit Board?
#define BUTTON_RIGHT 4   // 3
#define BUTTON_BOTTOM 3  // 4
#define BUTTON_LEFT 7    // 5
const uint8_t button_pins[] = {BUTTON_TOP, BUTTON_RIGHT, BUTTON_BOTTOM, BUTTON_LEFT};

// --- Helper defines ---

#define BUTTON_STATES_EV_DATA_LEN 2
#define NUMPIXELS 64
#define BUTTON_RELEASED 0
#define BUTTON_PRESSED 1

#define SPEC_TYPE_CIRC01 0x00  // Green circle 1 to identify labyrinth
#define SPEC_TYPE_CIRC02 0x01  // Green circle 2 to identify labyrinth
#define SPEC_TYPE_PLAYER 0x02  // white position of player
#define SPEC_TYPE_TARGET 0x03  // red pulsing position of target

// Color defines

#define MATRIX_COL_OFF 0x00
#define MATRIX_COL_PLAYER 0x02
#define MATRIX_COL_CIRC 0x03
#define MATRIX_COL_TARGET 0x04

uint8_t wall_positions[36] = {0x00};
uint8_t player_index = 0xFF;
uint8_t target_index = 0xFF;
uint8_t circ01_index = 0xFF;
uint8_t circ02_index = 0xFF;

uint8_t player_index_old = 0xFF;
uint8_t target_index_old = 0xFF;
uint8_t circ01_index_old = 0xFF;
uint8_t circ02_index_old = 0xFF;

EventBuffer<BUTTON_STATES_EV_DATA_LEN> button_states_ev_buf(CMDMS_BUTTON_STATES);
Adafruit_NeoPixel pixels(NUMPIXELS, MATRIX_DATA_IN, NEO_GRB + NEO_KHZ800);  // TODO: Check if NEO_KHZ800 is correct

// Commands which should be executed after module initialization (e.g. Force update states or change display)
void module_init_settings_local() {
}

// Translate position from 6x6 matrix to 8x8 matrix
uint8_t _6_to_8_matrix(uint8_t position) {
    // Serial.print("Position in der 6er Matrix");
    // Serial.println(position);

#ifdef ROTATE_90
    position = rotate_90(position);
#endif

#ifdef ROTATE_180
    position = rotate_180(position);
#endif

#ifdef ROTATE_270
    position = rotate_270(position);
#endif

    uint8_t x_6 = position / 6;
    uint8_t y_6 = position % 6;

    uint8_t x_8 = x_6 + 1;
    uint8_t y_8 = y_6 + 1;

    // Serial.print("Position in der 8er Matrix");
    // Serial.println(8 * y_8 + x_8);

    return 8 * x_8 + y_8;
}

#ifdef ROTATE_90
// in 6x6 matrix rotate position by 90° counter clockwise
uint8_t rotate_90(uint8_t position) {
    uint8_t x_6 = position / 6;
    uint8_t y_6 = position % 6;

    return 6 * (5 - y_6) + x_6;
}
#endif

#ifdef ROTATE_180
// in 6x6 matrix rotate position by 180° counter clockwise
uint8_t rotate_180(uint8_t position) {
    uint8_t x_6 = position / 6;
    uint8_t y_6 = position % 6;

    return 6 * (5 - x_6) + (5 - y_6);
}
#endif

#ifdef ROTATE_270
// in 6x6 matrix rotate position by 270° counter clockwise
uint8_t rotate_270(uint8_t position) {
    uint8_t x_6 = position / 6;
    uint8_t y_6 = position % 6;

    return 6 * y_6 + (5 - x_6);
}
#endif

// Translate position from 8x8 matrix to 6x6 matrix
// uint8_t game_to_real_matrix(uint8_t position) {
//     uint8_t x_8 = position / 8;
//     uint8_t y_8 = position % 8;

//     uint8_t x_6 = x_8 - 1;
//     uint8_t y_6 = y_8 - 1;

//     return 6*y_6 + x_6;
// }

void set_color(uint8_t red, uint8_t green, uint8_t blue, uint8_t index) {
    pixels.setPixelColor(index, pixels.Color(red, green, blue));
}

// TODO: Test if this is correct
void setBorderColor(uint8_t r, uint8_t g, uint8_t b) {
    // Top
    for (int i = 0; i < 8; i++) {
        pixels.setPixelColor(i, pixels.Color(g, r, b));
    }

    // Bottom
    for (int i = 56; i < 64; i++) {
        pixels.setPixelColor(i, pixels.Color(g, r, b));
    }

    // Left
    for (int i = 0; i < 64; i += 8) {
        pixels.setPixelColor(i, pixels.Color(g, r, b));
    }

    // Right
    for (int i = 7; i < 64; i += 8) {
        pixels.setPixelColor(i, pixels.Color(g, r, b));
    }

    pixels.show();
}

void rainbow_test(int count) {
    int r, g, b;
    pixels.setBrightness(5);
    for (int c = 0; c < count; c++) {
        for (int j = 0; j < 3; j += 1) {
            r = 0;
            g = 0;
            b = 0;
            if (j % 3 == 0) {
                r = 255;
            } else if (j % 3 == 1) {
                g = 255;
            } else {
                b = 255;
            }

            for (int i = 0; i < 64; i++) {
                pixels.setPixelColor(i, pixels.Color(r, g, b));
                pixels.show();
                delay(10);
            }
        }
    }
}

void update_buttonstates() {
    static uint8_t button_states_old[4] = {BUTTON_RELEASED, BUTTON_RELEASED, BUTTON_RELEASED, BUTTON_RELEASED};
    static uint8_t button_states[4];

    for (int i = 0; i < 4; i++) {
        // -- Read button pressed / released for current digital pin --
        if (digitalRead(button_pins[i]) == BUTTON_PRESSED) {
            button_states[i] = BUTTON_PRESSED;
        } else if (digitalRead(button_pins[i]) == BUTTON_RELEASED) {
            button_states[i] = BUTTON_RELEASED;
        }
    }

    // -- Check if button state is stable and has changed --
    bool changed = false;
    for (int i = 0; i < 4; i++) {
        if (button_states[i] != button_states_old[i]) {
            changed = true;
        } else {
            continue;
        }
    }

    // -- Update button states --
    if (changed) {
        uint8_t button_states_reg[] = {0x00};
        for (int i = 0; i < 4; i++) {
            button_states_old[i] = button_states[i];
            button_states_reg[0] += button_states[i] ? 0 : (1 << i);
        }

        Event<BUTTON_STATES_EV_DATA_LEN> button_states_ev{button_states_ev_buf.get_counter(), button_states_reg};
        button_states_ev_buf.add_event(button_states_ev);
    }
}

/*
 *  - Setting and clearing of wall positions works
 *
 */

void updateMatrix() {
    // Serial.print("Circ01index: ");
    // Serial.println(circ01_index);
    // Serial.print("Circ01indexOld: ");
    // Serial.println(circ01_index_old);

    // clear everything
    for (int i = 0; i < 36; i++) {
        set_color(0, 0, 0, _6_to_8_matrix(i));
    }

    set_color(0, 255, 0, _6_to_8_matrix(circ01_index));
    set_color(0, 255, 0, _6_to_8_matrix(circ02_index));
    set_color(255, 255, 255, _6_to_8_matrix(player_index));
    set_color(255, 0, 100, _6_to_8_matrix(target_index));

    // Check if any of the indices collide and if so, set mixed color
    if (player_index == circ01_index || player_index == circ02_index) {
        // Serial.println("player = circ");
        set_color(100, 255, 100, _6_to_8_matrix(player_index));  // Mix player color with circle color
    }
    if (circ01_index == target_index || circ02_index == target_index) {
        // Serial.println("circ = target");
        set_color(255, 255, 0, _6_to_8_matrix(target_index));  // Mix circle color with target color
    }
    if (player_index == target_index) {
        // Serial.println("player = target");
        set_color(255, 255, 255, _6_to_8_matrix(player_index));  // Mix player color with target color
    }

    if (player_index > 35) {
        set_color(0, 0, 0, _6_to_8_matrix(player_index_old));
    }

    if (circ01_index > 35) {
        // Serial.print("circ01 above 35: ");
        // Serial.println(circ01_index);
        set_color(0, 0, 0, _6_to_8_matrix(circ01_index_old));
    }

    if (circ02_index > 35) {
        set_color(0, 0, 0, _6_to_8_matrix(circ02_index_old));
    }

    if (target_index > 35) {
        set_color(0, 0, 0, _6_to_8_matrix(target_index_old));
    }

    // Set color for wall collisions (if any)
    for (int i = 0; i < 36; i++) {
        if (wall_positions[i] == 1) {
            set_color(255, 0, 0, _6_to_8_matrix(i));
        }
    }

    if (!selected) {
        // Serial.print("<");
        pixels.show();
        // Serial.print(">");
    } else {
        // Serial.println("X");
    }
}

void process_module_cmd(uint8_t &cmd, uint8_t &len, CircularBuffer<uint8_t, 8> &data) {
    switch (cmd) {
        case CMDMM_RG_LED: {
            if (len == 0x01) {
                uint8_t led_code = frame_data_buf.shift();
                digitalWrite(status_led_pins::GREEN, (led_code & (1 << 0)) ? LOW : HIGH);
                digitalWrite(status_led_pins::RED, (led_code & (1 << 1)) ? LOW : HIGH);
            } else {
                add_error_event(ERR_INVALID_DATA_LEN);
            }
        } break;  // Check which color code is already set in matrix and set appropriate mix color

        case CMDMM_ACK_BUTTON_STATES: {
            {
                if (len == 1) {
                    Event<2> button_states_ev = button_states_ev_buf.peek_event();
                    uint8_t bs_ev_buf_counter = button_states_ev.data_[0];
                    uint8_t ack_counter = frame_data_buf.shift();

                    if (bs_ev_buf_counter == ack_counter) {
                        button_states_ev_buf.remove_first_event();
                    } else {
                        add_error_event(ERR_ACK_MISMATCH);
                    }
                } else {
                    add_error_event(ERR_INVALID_DATA_LEN);
                }
                break;
            }
        }

        case CMDMM_RED_WALL_POSITIONS: {
            if (len == 0x05) {
                uint8_t matrix_index = 0;
                for (int i = 0; i < 5; i++) {
                    uint8_t wall_byte = frame_data_buf.shift();
                    int var;
                    if (i == 5)
                        var = 3;
                    else
                        var = 0;

                    for (int j = 7; j >= var; j--) {
                        // if (i >= 4 && j >= 4) break; // Only 36 pixels, The fifth byte only contains four bits
                        if (wall_byte & _BV(j)) {
                            wall_positions[matrix_index] = 1;
                            // Serial.print("Wallpos ");
                            // Serial.print(matrix_index);
                            // Serial.print(" : ");
                            // Serial.println(wall_positions[matrix_index]);
                        } else {
                            wall_positions[matrix_index] = 0;
                        }
                        matrix_index++;
                    }
                }

            } else {
                add_error_event(ERR_INVALID_DATA_LEN);
            }
        } break;

        case CMDMM_SPECIAL_POSITIONS: {
            uint8_t special_type = 0;
            uint8_t position = 0;
            if (len > 4 || len < 1) {
                add_error_event(ERR_INVALID_DATA_LEN);
            } else {
                uint8_t len_index = len;
                do {
                    uint8_t byte = frame_data_buf.shift();
                    special_type = byte >> 6;
                    position = byte & 0b00111111;

                    switch (special_type) {
                        case SPEC_TYPE_CIRC01:
                            // Serial.println("circ02");
                            circ01_index_old = circ01_index;
                            circ01_index = position;
                            break;

                        case SPEC_TYPE_CIRC02:
                            // Serial.println("circ02");
                            circ02_index_old = circ02_index;
                            circ02_index = position;
                            break;

                        case SPEC_TYPE_PLAYER:
                            player_index_old = player_index;
                            player_index = position;
                            // Serial.println("player");
                            break;

                        case SPEC_TYPE_TARGET:
                            target_index_old = target_index;
                            // Serial.println("target");
                            target_index = position;
                            break;

                        default:
                            // Serial.print("Special Type not known ");
                            // Serial.println(special_type);
                            //  TODO error handling
                            break;
                    }
                    len_index--;
                } while (len_index > 0);
            }

        } break;

        default:
            Serial.println("Error invalid command ");
            add_error_event(ERR_INVALID_CMD);
            break;
    }
    data.clear();
}

void setup() {
    // --Setup SPI connection--
    module_setup();

    // Init Status LED
    status_led_init();
    status_led_blue();

    pinMode(BUTTON_TOP, INPUT_PULLUP);
    pinMode(BUTTON_RIGHT, INPUT_PULLUP);
    pinMode(BUTTON_BOTTOM, INPUT_PULLUP);
    pinMode(BUTTON_LEFT, INPUT_PULLUP);

    // Setup pixel matrix
    pinMode(MATRIX_DATA_IN, OUTPUT);

    pixels.begin();

    // rainbow_test(3);            // For debugging
    // setBorderColor(0, 0, 150);  // blue not ; For debugging; Not visible in case
    pixels.setBrightness(100);

    pixels.show();
}

Timer buttonTimer(20);

void loop() {
    // Update buttonstates if necessary
    if (buttonTimer.tick()) {
        update_buttonstates();
        updateMatrix();
    }

    if (!ready) {
#ifdef DEBUG_PRINT_BUFFER_AFTER_EXCHANGE
        Serial.print("EXCHANGE: (tx left: ");
        Serial.print(send_buffer.size());
        Serial.print(") rec:  ");
        print_rx_buffer();
#endif

        // --Validation and proccess of received frames--
        validate_and_process_frames(process_module_cmd);
        send_buffer.clear();

        // --Build send buffer--
        // Go through all event buffers and push new events to send_buffer
        if (module_initialized == false) {
            module_init(MODULE_ID, MODULE_VERSION);
        } else {
            push_ev_to_send_buf<BUTTON_STATES_EV_DATA_LEN, TX_BUFFER_SIZE>(button_states_ev_buf, send_buffer);
            push_ev_to_send_buf<ERROR_EV_DATA_LEN, TX_BUFFER_SIZE>(error_ev_buf, send_buffer);
        }

#ifdef DEBUG_PRINT_BUFFER_AFTER_EXCHANGE
        Serial.print(" next send: ");
        print_tx_buffer();
        Serial.println();
#endif

        ready = true;
    }
}

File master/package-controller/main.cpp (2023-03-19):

// SPI Master Interface
#include <bcm2835.h>
#include <stdio.h>

#include <bitset>
#include <cassert>
#include <iostream>
#include <list>
#include <vector>

#include "crc.cpp"
#include "server.cpp"
#include "spi.cpp"

#define MAX_SLAVES 13

using namespace std;

int g_module_pos; // module position for usage across functions
struct package // custom struct for packages
{
    char cmd;
    char len;
    char *data;
    char crc;

    package(char cmd, char len, char *data, char crc)
    {
        this->cmd = cmd;
        this->len = len;
        this->data = data;
        this->crc = crc;
    }
    package(char cmd, char len, char *data)
    {
        this->cmd = cmd;
        this->len = len;
        this->data = data;
        this->crc = calcCRC(cmd, len, data);
    }
};

std::list<package> list_array_miso[MAX_SLAVES] = {}; // List for incoming packages for all slaves
std::list<package> list_array_mosi[MAX_SLAVES] = {}; // List for outgoing packages for all slaves
vector<char> socketInBuffer = {};
vector<char> socketOutBuffer = {};
char connectedModules[5] = {255, 1, 2, 0, 0}; // custom package for connected modules
char prevConnectedModules[5] = {255, 1, 2, 0, 0};

void sendError(char pos, char code) // function to create error codes
{
    socketOutBuffer.push_back(0xFF);
    socketOutBuffer.push_back(0xFE);
    socketOutBuffer.push_back(0x02);
    socketOutBuffer.push_back(pos);
    socketOutBuffer.push_back(code);
}

void socketInToMosi() // convert buffers received via TCP to packages for slaves
{
    if (socketInBuffer.size() == 0)
    {
        return;
    }
    while (socketInBuffer.size() >= 1)
    {
        char slave = socketInBuffer.back(); // extract slave
        socketInBuffer.pop_back();
        char cmd = socketInBuffer.back(); // extract command
        socketInBuffer.pop_back();
        char len = socketInBuffer.back(); // extract length
        socketInBuffer.pop_back();
        char *data;
        if (len == 0)
            data = nullptr;
        if (len > 0)
        {
            data = new char[len];
            for (int i = 0; i < len; i++)
            {
                data[i] = socketInBuffer.back(); // extract data
                socketInBuffer.pop_back();
            }
        }
        package p(cmd, len, data); // create package
        if (slave >= MAX_SLAVES)
        {
            sendError(0xFF, 10);
            cout << "Send Error slave out of range" << endl;
        }
        else
        {
            list_array_mosi[slave].push_back(p); // add package to outgoing buffer for the correct slave
        }
    }
    for (int i = 0; i < MAX_SLAVES; i++)
    {
        list_array_mosi[i].reverse(); // reverse the package order to mirror the received order
    }
}

void misoToSocketOut() // convert packages to vector for TCP
{
    for (int i = 0; i < MAX_SLAVES; i++)
    {
        list_array_miso[i].reverse(); // reverse the package order to mirror the received order
        while (list_array_miso[i].size() > 0)
        {
            package p = list_array_miso[i].back();
            list_array_miso[i].pop_back();
            socketOutBuffer.push_back(i); // add position
            socketOutBuffer.push_back(p.cmd); // add command
            socketOutBuffer.push_back(p.len); // add length
            for (int j = 0; j < p.len; j++) 
            {
                socketOutBuffer.push_back(p.data[j]); // add data
            }
        }
    }
}

const list<package> transmit(const list<package> &packages, int module_pos) // function for SPI exchange
{
    vector<char> outBuffer;
    vector<char> ackBuffer;
    for (auto &p : packages) // convert all packages for client to a vector
    {
        outBuffer.push_back(p.crc);
        for (int i = 0; i < p.len; i++)
        {
            outBuffer.push_back(p.data[p.len - i - 1]);
        }
        outBuffer.push_back(p.len);
        outBuffer.push_back(p.cmd);
        delete[] p.data;
    }
    vector<char> inBuffer; // create buffer for incoming data
    inBuffer.reserve(outBuffer.capacity());

    list<package> packagesIn;

    enum state
    {
        CMD = 0,
        LEN = 1,
        DATA = 2,
        CRC = 3
    };

    state currentState = CMD;
    char len = 0;
    bool end;
    bool error = false;
    int i = 0;
    int iterations = 0;

    do
    {
        end = false;
        char out = 0x00;
        if (outBuffer.size() > 0)
        {
            out = outBuffer.back(); // get last byte from vector
            outBuffer.pop_back();
        }
        char in = bcm2835_spi_transfer(out); // exchange one byte
        iterations++;
        // printf("pos: %x, out: %x, in: %x, state: %x \n", g_module_pos, out, in, currentState); // function to print exchanged data

        if (currentState == CMD) // waiting for command
        {
            if (in == 0x00)
            {
                i++;
                if (i >= 2)
                {
                    end = true;
                }
            }
            else if (in == 0xFF) // error
            {
                end = true;
                error = true;
            }
            else // normal command
            {
                inBuffer.push_back(in);
                currentState = LEN;
            }
        }
        else if (currentState == LEN) // waiting for len
        {
            inBuffer.push_back(in);
            len = in;
            currentState = len ? DATA : CRC;
        }
        else if (currentState == DATA) // waiting for data
        {
            inBuffer.push_back(in);
            len--;
            if (len == 0)
            {
                currentState = CRC;
            }
        }
        else if (currentState == CRC) // waiting for crc
        {
            inBuffer.push_back(in);
            currentState = CMD;

            // check CRC, if correct put ACK in out Buffer, else put CRC Error in out Buffer; clear in buffer
            {
                char cmd = inBuffer.at(0);
                char len = inBuffer.at(1);
                char *data = new char[len];
                for (int i = 0; i < len; i++)
                {
                    data[i] = inBuffer.at(i + 2);
                }
                char crc = inBuffer.at(len + 2);
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

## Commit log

2023-03-19 repo migration
    [CM-01_circuit.kicad_pcb, CM-01_circuit.kicad_sch, CM-01_circuit.sch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]
2023-03-21 cleanup circuit
    [CM-01_circuit.sch, case.kicad_pcb, case.kicad_sch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]
2023-03-21 3d design moved
    [CM01-ModuleBottom.stl, CM01-ModuleTop.stl, CM01-Xled.stl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]
2023-03-21 rename module connector
    [case.kicad_pcb, case.kicad_sch]
2023-03-28 Updated files for release
    [CM-01_circuit.kicad_pcb, CM-01_circuit.kicad_sch, simon_says.kicad_pcb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]
